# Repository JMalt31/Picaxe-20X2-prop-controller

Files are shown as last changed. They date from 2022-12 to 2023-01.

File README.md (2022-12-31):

# Picaxe-20X2-prop-controller
This is a prop or robot controller based on the picaxe 20X2 Microcontroller. 
This PCB was created with kiCad 6.0
I find this system much easier to use then the Arduino. I also have not found anything that the Arduino can do that this controller cannot do. 
The Picaxe get a bad rap for being a quote "less powerful or beginner Micocontroller" when that is simply not the case. 
There is also a Picaxe board that has the Arduino form factor and can use Arduino shields. 
If I need something that the Picaxe cannot handle then I will use the ESP32 controller which can also be programmed in Python.

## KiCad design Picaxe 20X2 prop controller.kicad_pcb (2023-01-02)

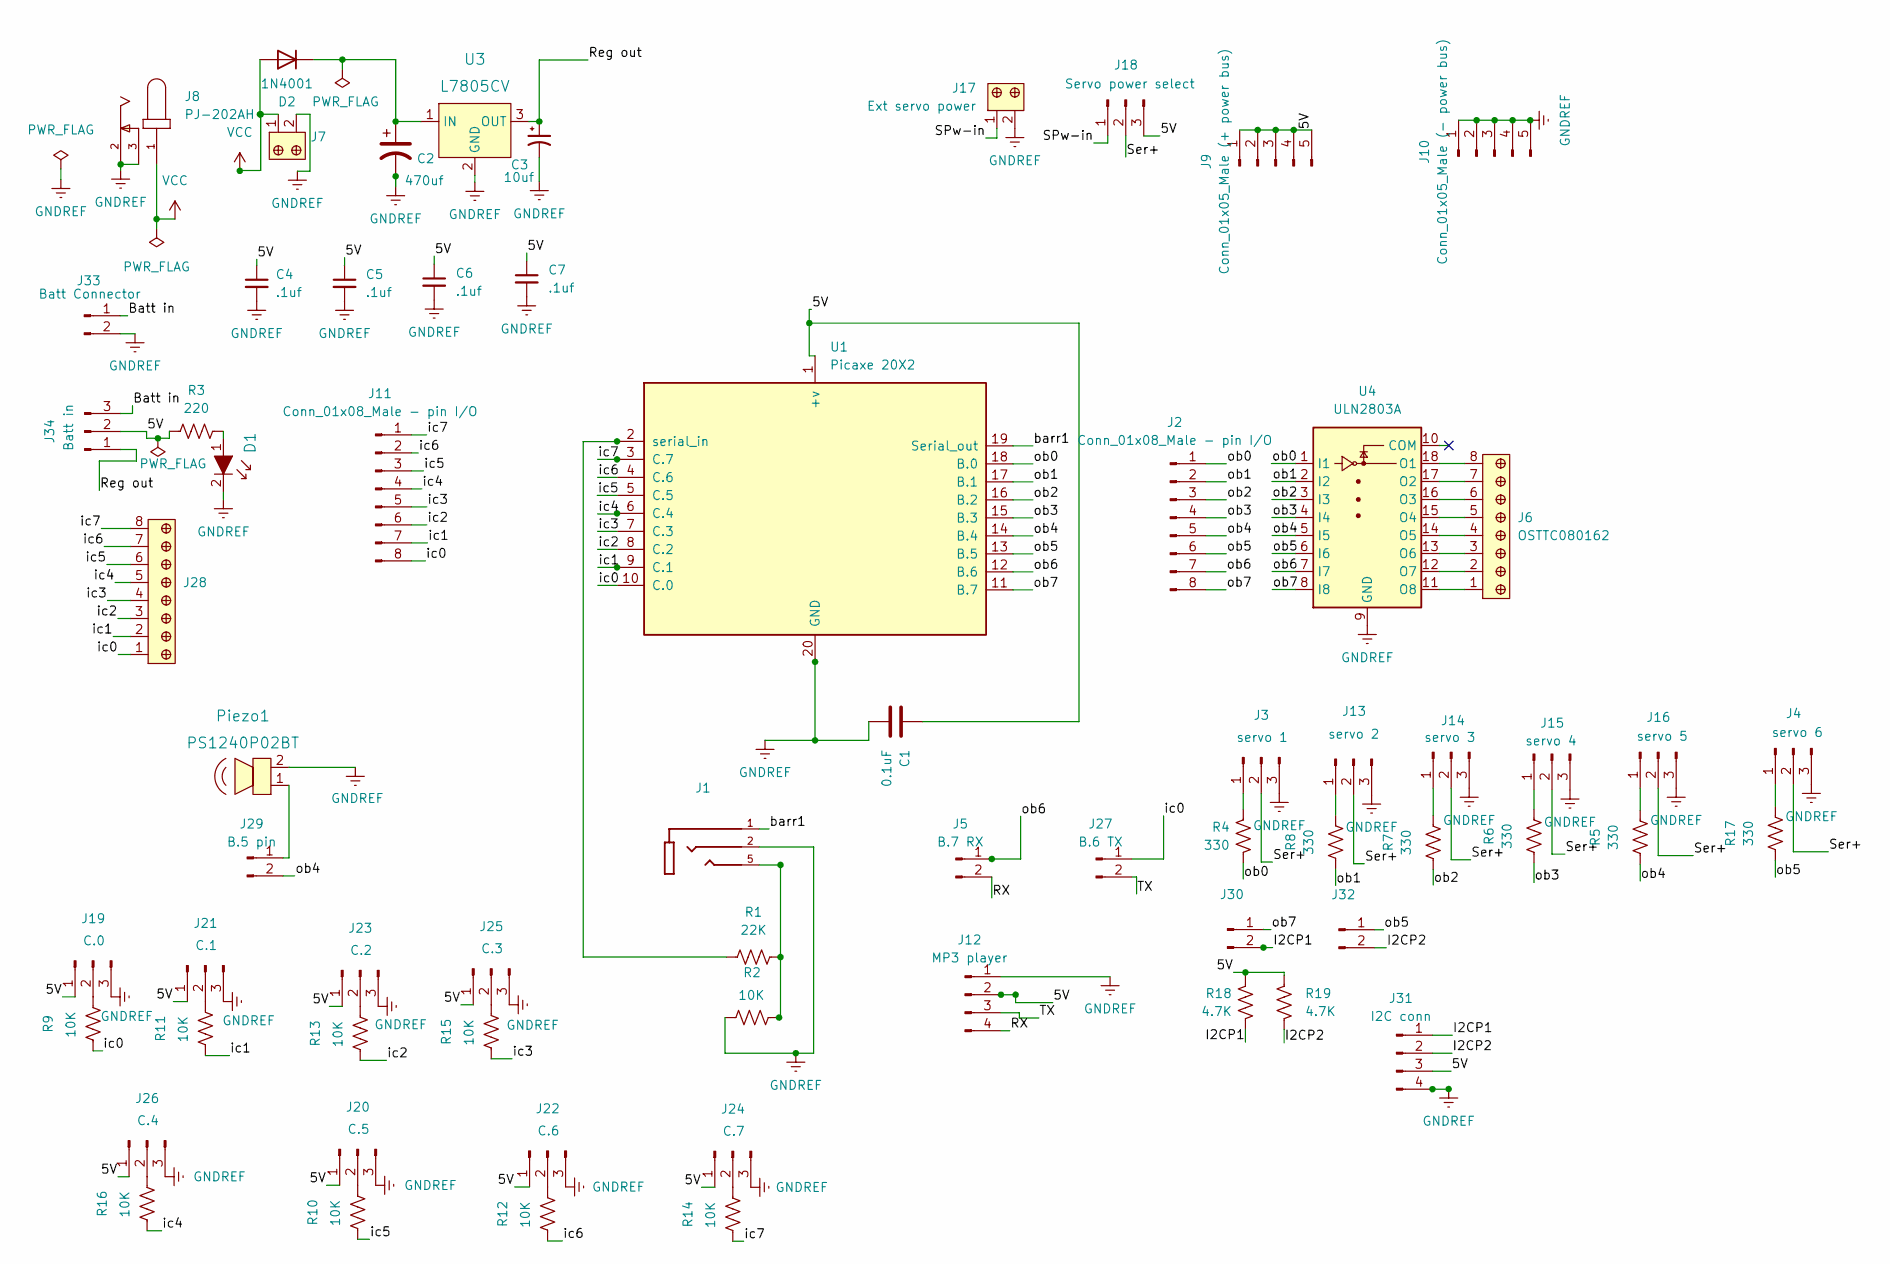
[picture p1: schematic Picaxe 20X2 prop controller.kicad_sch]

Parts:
C1: 0.1uF; C_Disc_D5.0mm_W2.5mm_P5.00mm
C2: 470uf; CP_Radial_D10.0mm_P5.00mm
C3: 10uf; CP_Radial_D5.0mm_P2.50mm
C4, C5, C6, C7: .1uf; C_Disc_D3.0mm_W2.0mm_P2.50mm
D1: LTL2R3KEK; LED_5mm_Radial; MPN LTL2R3KEK; Digi-Key_PN 160-1682-ND
D2: 1N4001; D_DO-41_SOD81_P10.16mm_Horizontal
J1: FC68131; CLIFF_FC68131; PARTREV 5
J2, J11: Conn_01x08_Male - pin I/O; PinHeader_1x08_P2.54mm_Vertical
J3: servo 1; PinHeader_1x03_P2.54mm_Vertical
J4: servo 6; PinHeader_1x03_P2.54mm_Vertical
J5: B.7 RX; PinHeader_1x02_P2.54mm_Vertical
J6, J28: OSTTC080162; Term_Block_1x8_P5mm; MPN OSTTC080162; Digi-Key_PN ED2606-ND
J7: OSTTC020162; Term_Block_1x2_P5mm; MPN OSTTC020162; Digi-Key_PN ED2600-ND
J8: PJ-202AH; CUI_PJ-202AH; PART_REV 1.02
J9: Conn_01x05_Male (+ power bus); PinHeader_1x05_P2.54mm_Vertical
J10: Conn_01x05_Male (- power bus); PinHeader_1x05_P2.54mm_Vertical
J12: MP3 player; Catalex MP3 player board
J13: servo 2; PinHeader_1x03_P2.54mm_Vertical
J14: servo 3; PinHeader_1x03_P2.54mm_Vertical
J15: servo 4; PinHeader_1x03_P2.54mm_Vertical
J16: servo 5; PinHeader_1x03_P2.54mm_Vertical
J17: Ext servo power; Term_Block_1x2_P5mm; MPN OSTTC020162; Digi-Key_PN ED2600-ND
J18: Servo power select; PinHeader_1x03_P2.54mm_Vertical
J19: C.0; PinHeader_1x03_P2.54mm_Vertical
J20: C.5; PinHeader_1x03_P2.54mm_Vertical
J21: C.1; PinHeader_1x03_P2.54mm_Vertical
J22: C.6; PinHeader_1x03_P2.54mm_Vertical
J23: C.2; PinHeader_1x03_P2.54mm_Vertical
J24: C.7; PinHeader_1x03_P2.54mm_Vertical
J25: C.3; PinHeader_1x03_P2.54mm_Vertical
J26: C.4; PinHeader_1x03_P2.54mm_Vertical
J27: B.6 TX; PinHeader_1x02_P2.54mm_Vertical
J29: B.5 pin; PinHeader_1x02_P2.54mm_Vertical
J30: B.7; PinHeader_1x02_P2.54mm_Vertical
J31: I2C conn; PinHeader_1x04_P2.54mm_Vertical
J32: B.5; PinHeader_1x02_P2.54mm_Vertical
J33: Batt Connector; PinHeader_1x02_P2.54mm_Vertical
J34: Batt in; PinHeader_1x03_P2.54mm_Vertical
Piezo1: PS1240P02BT; Piezo_Transducer_THT_PS1240P02BT; MPN PS1240P02BT; Digi-Key_PN 445-2525-1-ND
R1: 22K; R_Axial_DIN0207_L6.3mm_D2.5mm_P10.16mm_Horizontal
R2, R9, R10, R11, R12, R13, R14, R15, R16: 10K; R_Axial_DIN0207_L6.3mm_D2.5mm_P10.16mm_Horizontal
R3: 220; R_Axial_DIN0207_L6.3mm_D2.5mm_P10.16mm_Horizontal
R4, R5, R6, R7, R8, R17: 330; R_Axial_DIN0207_L6.3mm_D2.5mm_P10.16mm_Horizontal
R18, R19: 4.7K; R_Axial_DIN0207_L6.3mm_D2.5mm_P10.16mm_Horizontal
U1: Picaxe 20X2; DIP-20_W7.62mm_LongPads
U3: L7805CV; TO-220-3; MPN L7805CV; Digi-Key_PN 497-1443-5-ND
U4: ULN2803A; DIP-18_W7.62mm_LongPads

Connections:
/5V: C1.1, C4.1, C5.1, C6.1, C7.1, J9.1, J9.2, J9.3, J9.4, J9.5, J12.2, J18.3, J19.1, J20.1, J21.1, J22.1, J23.1, J24.1, J25.1, J26.1, J31.3, J34.2, R3.2, R18.2, R19.1, U1.1 (+v)
/Batt in: J33.1, J34.3
/I2CP1: J30.2, J31.1, R18.1
/I2CP2: J31.2, J32.2, R19.2
/RX: J5.2, J12.4
/Reg out: C3.1, J34.1, U3.3 (OUT)
/SPw-in: J17.1, J18.1
/Ser+: J3.2, J4.2, J13.2, J14.2, J15.2, J16.2, J18.2
/TX: J12.3, J27.2
/barr1: J1.1, U1.19 (Serial_out)
/ic0: J11.8, J27.1, J28.1, R9.2, U1.10 (C.0)
/ic1: J11.7, J28.2, R11.2, U1.9 (C.1)
/ic2: J11.6, J28.3, R13.2, U1.8 (C.2)
/ic3: J11.5, J28.4, R15.2, U1.7 (C.3)
/ic4: J11.4, J28.5, R16.2, U1.6 (C.4)
/ic5: J11.3, J28.6, R10.2, U1.5 (C.5)
/ic6: J11.2, J28.7, R12.2, U1.4 (C.6)
/ic7: J11.1, J28.8, R14.2, U1.3 (C.7)
/ob0: J2.1, R4.1, U1.18 (B.0), U4.1 (I1)
/ob1: J2.2, R8.2, U1.17 (B.1), U4.2 (I2)
/ob2: J2.3, R7.2, U1.16 (B.2), U4.3 (I3)
/ob3: J2.4, R6.2, U1.15 (B.3), U4.4 (I4)
/ob4: J2.5, J29.2, R5.2, U1.14 (B.4), U4.5 (I5)
/ob5: J2.6, J32.1, R17.2, U1.13 (B.5), U4.6 (I6)
/ob6: J2.7, J5.1, U1.12 (B.6), U4.7 (I7)
/ob7: J2.8, J30.1, U1.11 (B.7), U4.8 (I8)
GNDREF: C1.2, C2.2, C3.2, C4.2, C5.2, C6.2, C7.2, D1.2, J1.2, J3.3, J4.3, J7.2, J8.2, J8.3, J10.1, J10.2, J10.3, J10.4, J10.5, J12.1, J13.3, J14.3, J15.3, J16.3, J17.2, J19.3, J20.3, J21.3, J22.3, J23.3, J24.3, J25.3, J26.3, J31.4, J33.2, Piezo1.2, R2.2, U1.20 (GND), U3.2 (GND), U4.9 (GND)
unnamed: C2.1, D2.1 (K), U3.1 (IN)
unnamed: D1.1, R3.1
unnamed: J1.5, R1.1, R2.1
unnamed: J3.1, R4.2
unnamed: J4.1, R17.1
unnamed: J6.1, U4.11 (O8)
unnamed: J6.2, U4.12 (O7)
unnamed: J6.3, U4.13 (O6)
unnamed: J6.4, U4.14 (O5)
unnamed: J6.5, U4.15 (O4)
unnamed: J6.6, U4.16 (O3)
unnamed: J6.7, U4.17 (O2)
unnamed: J6.8, U4.18 (O1)
unnamed: J13.1, R8.1
unnamed: J14.1, R7.1
unnamed: J15.1, R6.1
unnamed: J16.1, R5.1
unnamed: J19.2, R9.1
unnamed: J20.2, R10.1
unnamed: J21.2, R11.1
unnamed: J22.2, R12.1
unnamed: J23.2, R13.1
unnamed: J24.2, R14.1
unnamed: J25.2, R15.1
unnamed: J26.2, R16.1
unnamed: J29.1, Piezo1.1
unnamed: R1.2, U1.2 (serial_in)
VCC: D2.2 (A), J7.1, J8.1

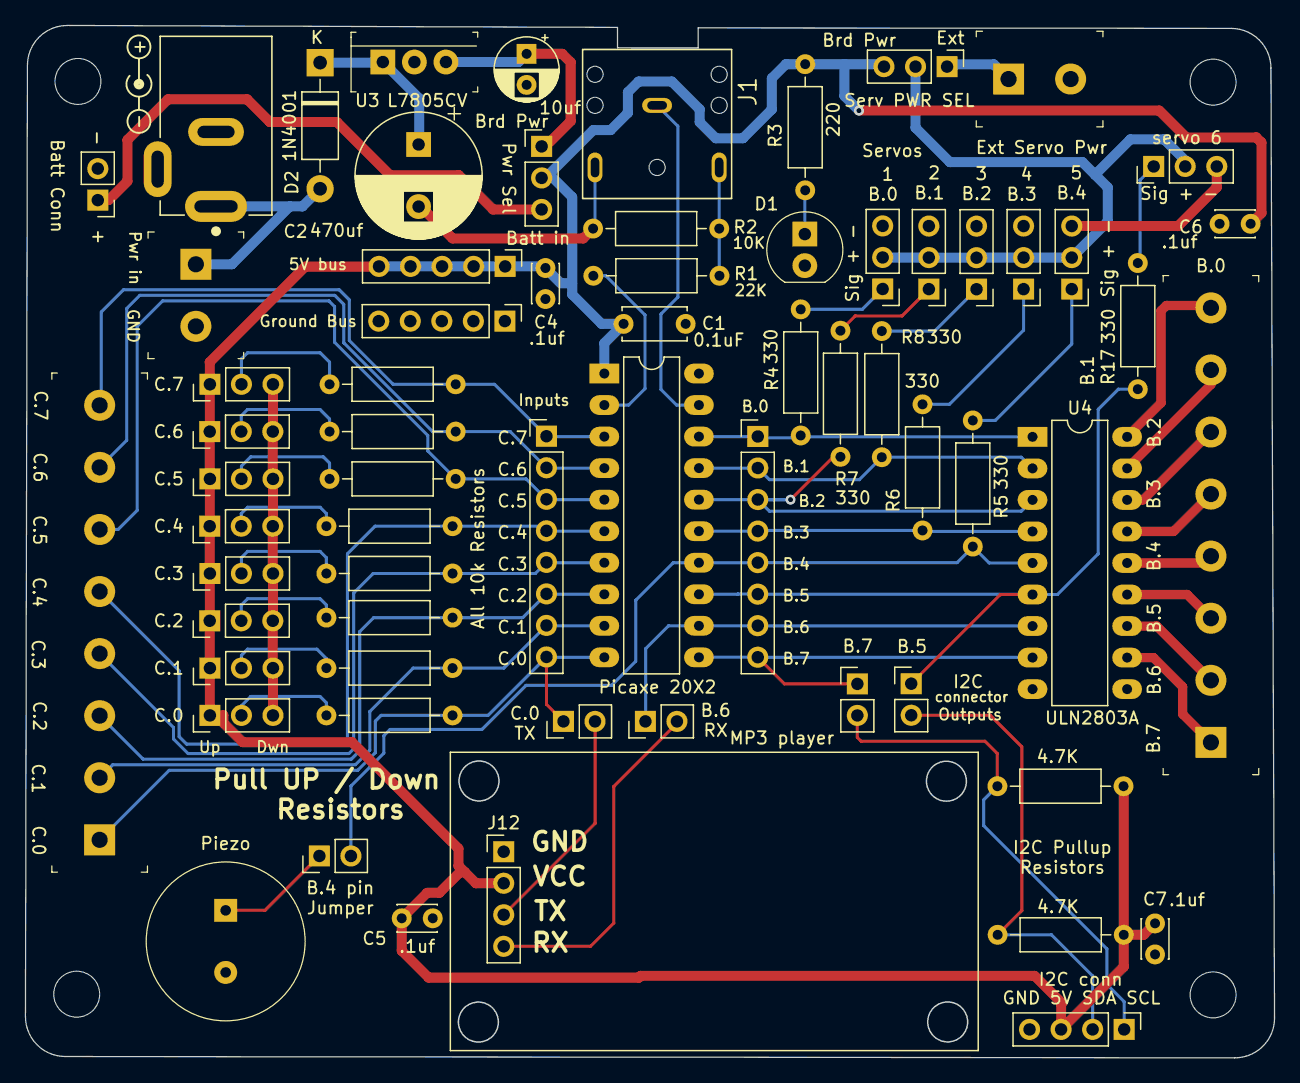
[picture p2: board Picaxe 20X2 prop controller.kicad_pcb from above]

Board: 2 copper layers, 100.6 x 83.2 mm, 66 parts (0 on the bottom side), 55 nets.

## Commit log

2022-12-17 my first commit
    [Picaxe 20X2 prop controller.kicad_pcb, Picaxe 20X2 prop controller.kicad_sch]
2022-12-18 added the 8 pin terminal block to the inputs
    [Picaxe 20X2 prop controller.kicad_pcb, Picaxe 20X2 prop controller.kicad_sch]
2022-12-18 added a piezo and b.5 select jumper
    [Picaxe 20X2 prop controller.kicad_pcb]
2022-12-18 forgot to save the schematic file after added the peizo and jumper
    [Picaxe 20X2 prop controller.kicad_sch]
2022-12-18 test of git diff
    [Picaxe 20X2 prop controller.kicad_sch]
2022-12-31 Move 20X2 to Git
    Will branch to see about moving the I2C connector
    [Picaxe 20X2 prop controller.kicad_pcb, Picaxe 20X2 prop controller.kicad_sch]
2022-12-31 Moved I2C connector and started to add a battery select
    Created a branch to move the I2C connector
    [Picaxe 20X2 prop controller.kicad_pcb, Picaxe 20X2 prop controller.kicad_sch]
2023-01-01 Moved I2c connector and added battery select option
    Added a battery connector and a select jumper to switch between the onboard regulator and the battery input connector. I also moved the I2C connector and added jumpers to disconnect the pins if neede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
    [Picaxe 20X2 prop controller.kicad_pcb, Picaxe 20X2 prop controller.kicad_sch]
2023-01-02 Added battery input polarity and changed 10uF to 2.4mm pin spacing
    [Picaxe 20X2 prop controller.kicad_pcb]
2023-01-02 Board complete Beta test 1
    [Picaxe 20X2 prop controller.kicad_pcb, Picaxe 20X2 prop controller.kicad_sch]
